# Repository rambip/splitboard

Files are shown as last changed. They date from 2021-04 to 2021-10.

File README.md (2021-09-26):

# Splitboard

This is the ressources we use to create our split, type matrix, bluetooth, mecanical custom keyboard.

Still in construction !

We used a lot of different technologies (solidworks for example), so you probably will not be able to recreate exactly the same keyboard.

But we added ressources you can use if you want to make your own !

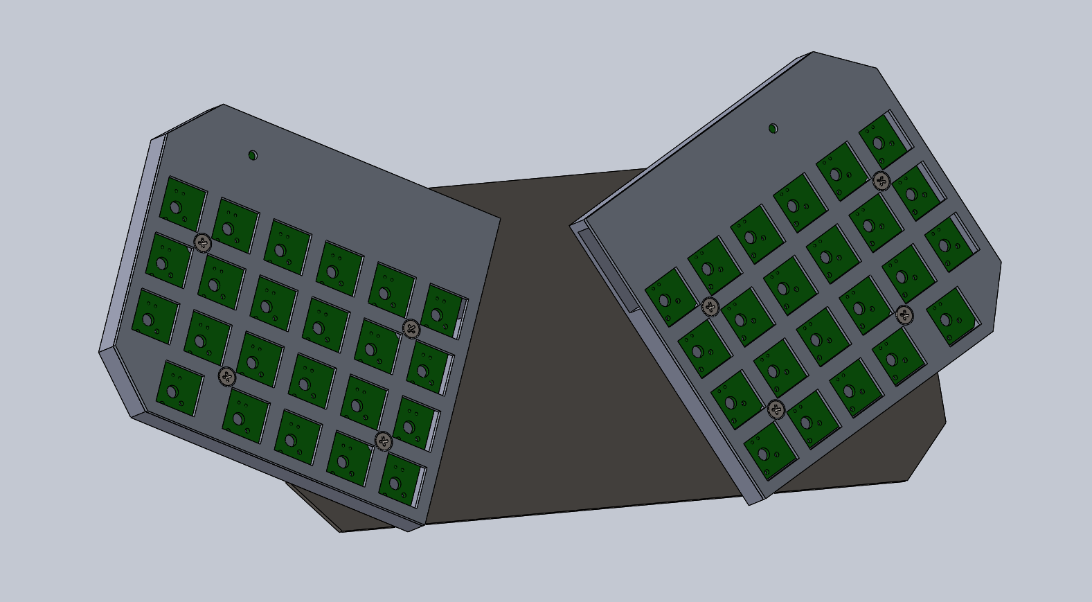
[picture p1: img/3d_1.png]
3d model


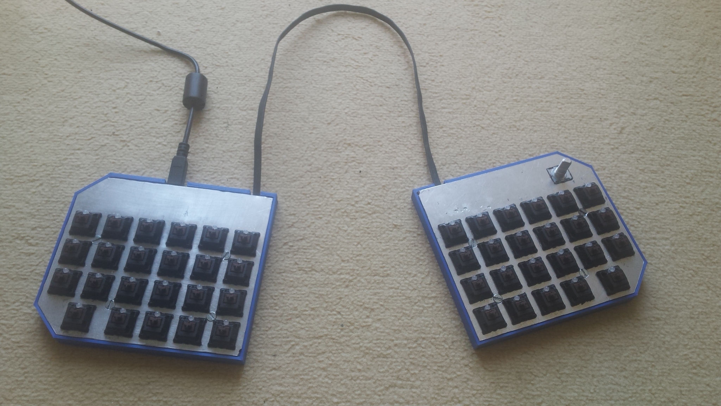
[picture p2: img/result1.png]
result1


## Description

pcb + 3d-printed box + aluminium plate + brown switches + adafruit feather 32u4

### Design goals:

- comfortable
	Ergonomics was the first goal of this model.
	Even if we had to make tradeoffs, the first choices (2 parts, mechanical switches, design of a new layout) were made to increase comfort.

- portable
	It is a tiny keyboard: 46 keys, measure less than 24x12 cm
	Every key has to be reachable without moving your hands at all !

- robust
	I didn't broke it yet !

- usb and bluetooth
        You can use it with any computer (mac or pc) and any modern smartphone

Our keyboard supports usb and bluetooth (BLE) communication with the *hid* specification.

## Content:

 - board design, with all components (kicad and gerber files) → `pcb`
 - ready to print STL files → `printing`
 - 3d modeling of the entire keyboard (solidworks and .step) → `3d`
 - arduino code for card → `code`

## 3d structure:

- box

- pcb

- plate

- switches

We chose the [cherry mx brown](https://www.cherrymx.de/en/mx-original/mx-brown.html).

> Pro tip: Before buying, try to find a second-hand broken keyboard somewhere !

## PCB and electronics:

We used the [adafruit 32u4](https://learn.adafruit.com/adafruit-feather-32u4-bluefruit-le/overview).

Go check out their [github account](https://github.com/adafruit), they have a lot of cool stuff !

## Software:

### Arduino

you can test our sketches if you have a 32u4 adafruit feather.

linux with arduino-cli:

First, make sure you are part of the `uucp` group.
If not, use the command `gpasswd -a $USER uucp`

`arduino-cli core install adafruit:avr`

find the board connected to usb (look at the *Port* path):
`arduino-cli board list` 

`arduino-cli board attach adafruit:avr:feather32u4`
`arduino-cli compile`
`arduino-cli upload`

### Ressources:
https://wiki.osdev.org/USB_Human_Interface_Devices

## TODO:

- [ ] convert all 3d modeling to .step
- [ ] add links to documentation

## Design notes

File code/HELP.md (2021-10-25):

# Help with `arduino-cli` 
If you want to use `arduino-cli` to compile this project, here is a guide:

- installation:
```
# install the avr platform 
arduino-cli core install arduino:avr

# install the adafruit core
arduino-cli core install adafruit:avr --additional-urls https://www.adafruit.com/package_adafruit_index.json

# install lib
arduino-cli lib install "Adafruit BluefruitLE nRF5"

```

- test if board is connected:
```
# test if board detected
arduino-cli board list
```

- compile and upload a sketch:
```
# create sketch.json
arduino-cli attach adafruit:avr:feather32u4
arduino-cli compile 
arduino-cli upload
```

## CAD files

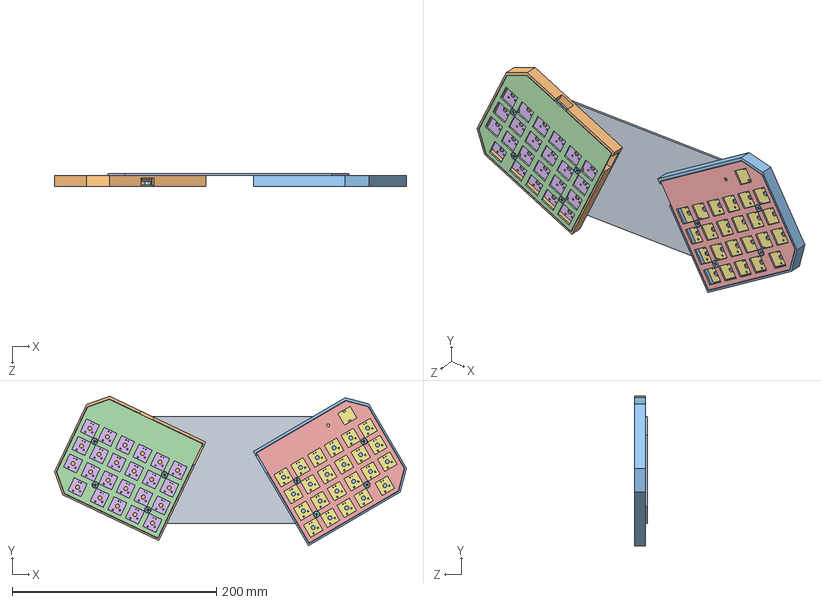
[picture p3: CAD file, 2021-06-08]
3d/Assemblage.STEP
344.8 x 146.5 x 13.1 mm
support
left back
right back
left plate
right plate
left pcb
right pcb
screw_ISO 7046-1 - M3 x 4 - Z - 4N x 8
spacer x 8

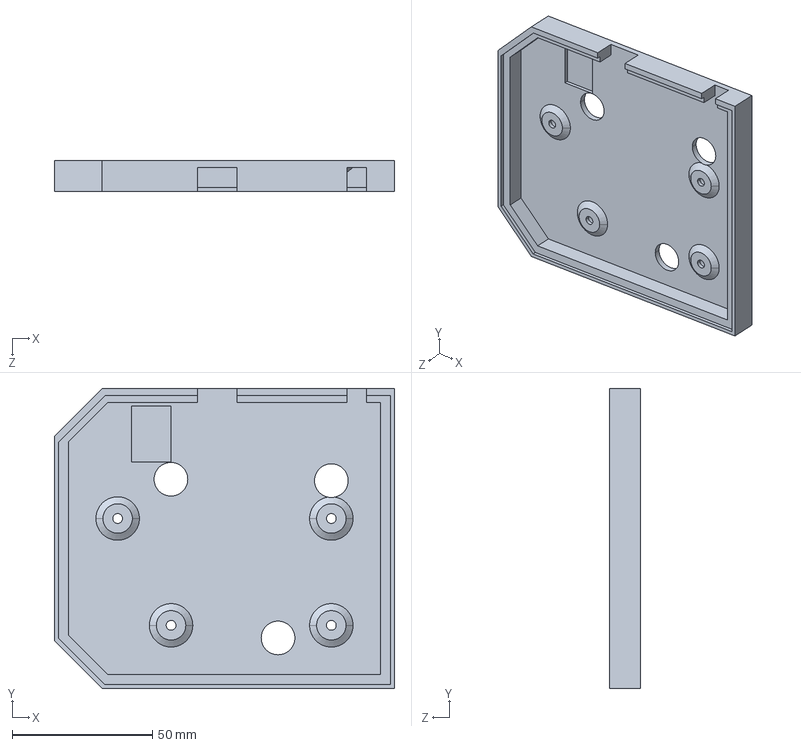
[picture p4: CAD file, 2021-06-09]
3d/left back.STEP
121.3 x 107.0 x 11.1 mm

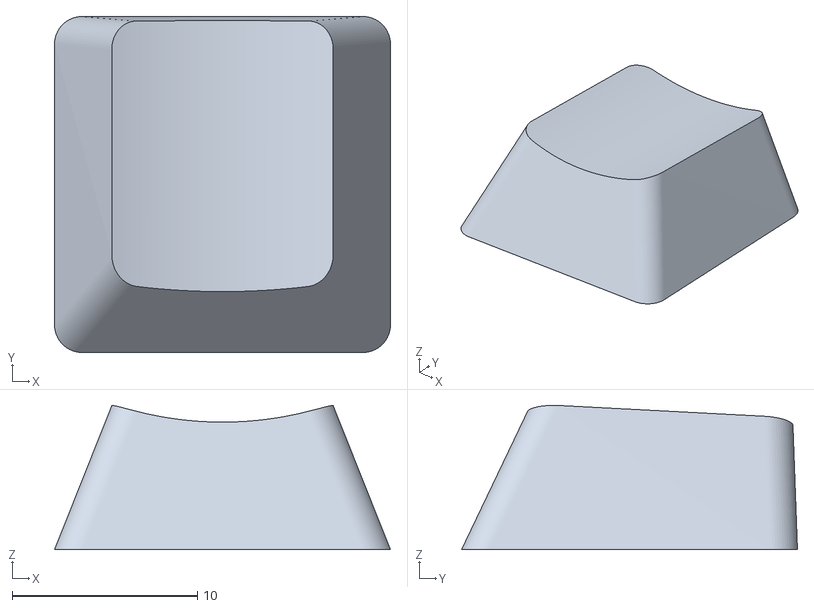
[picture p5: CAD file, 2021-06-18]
printing/keycaps/row_2.stl
18.2 x 18.2 x 7.80

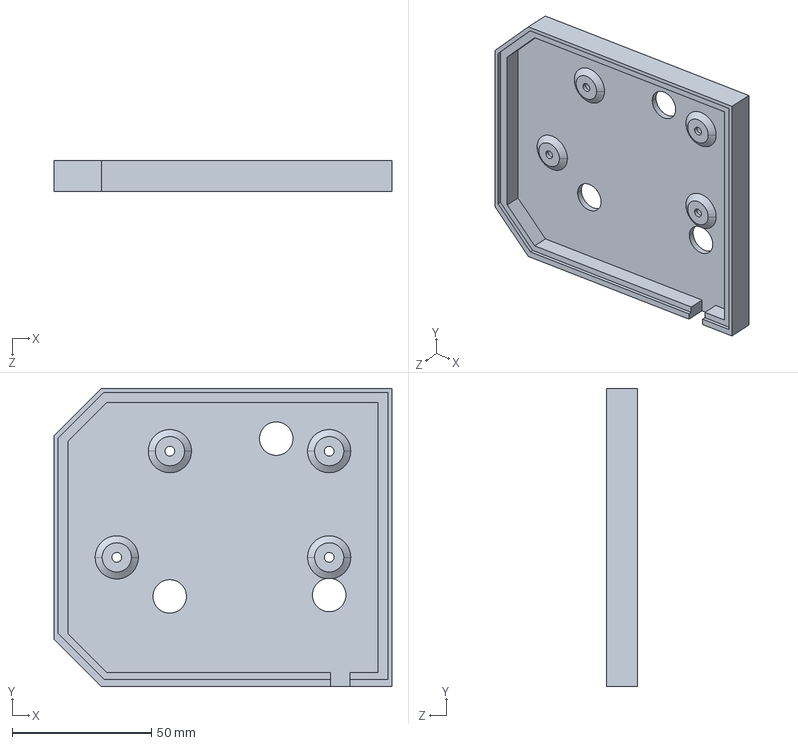
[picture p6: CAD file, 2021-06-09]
3d/right back.STEP
121.3 x 107.0 x 11.1 mm

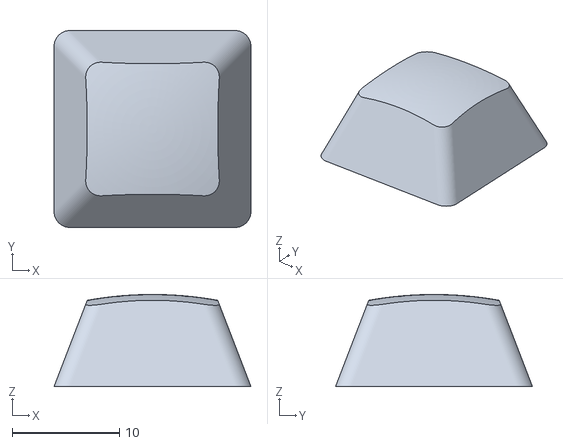
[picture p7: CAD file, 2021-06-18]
printing/keycaps/thumb.stl
18.4 x 18.4 x 8.60

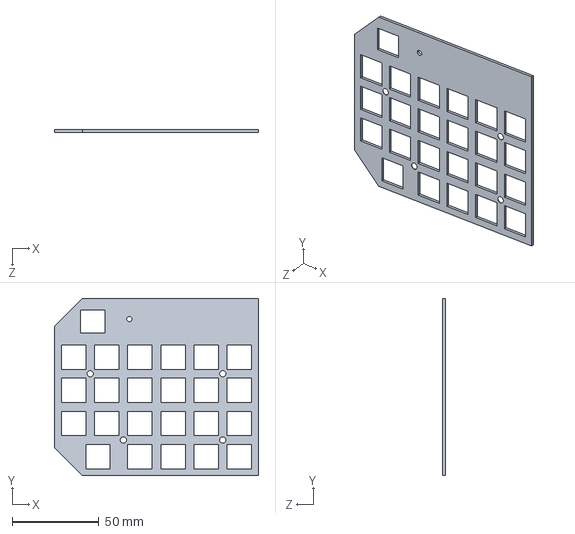
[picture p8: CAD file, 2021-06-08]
3d/right plate.STEP
117.2 x 102.0 x 1.50 mm

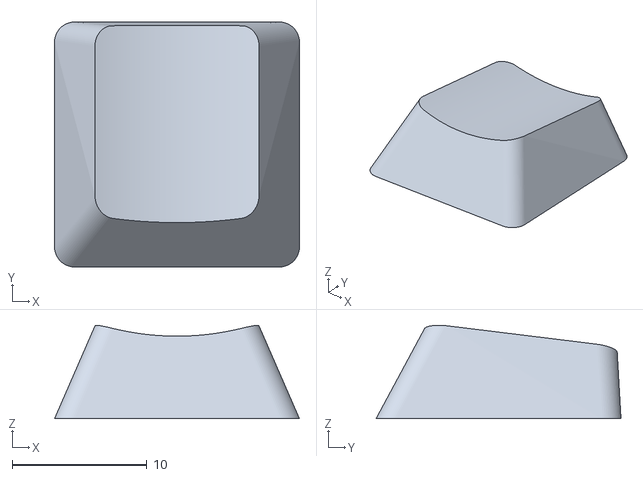
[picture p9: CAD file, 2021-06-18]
printing/keycaps/row_3.stl
18.2 x 18.2 x 6.92

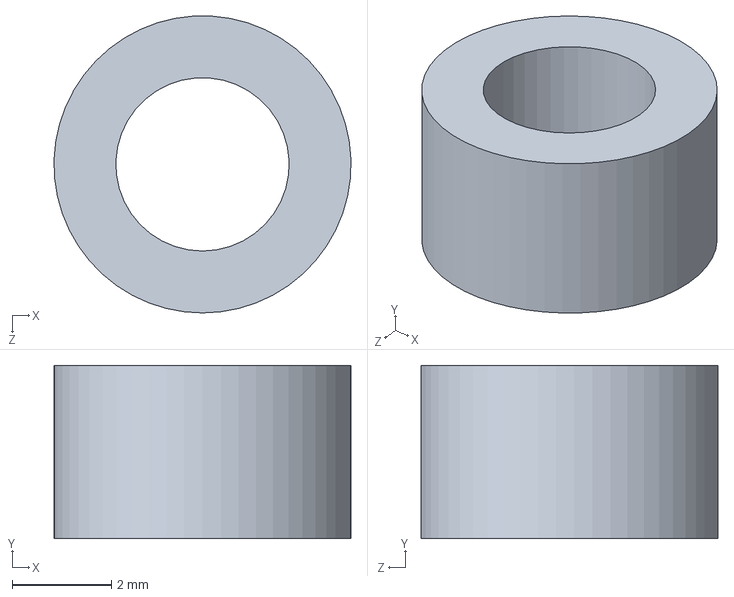
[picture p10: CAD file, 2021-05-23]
3d/spacer.SLDPRT
6.00 x 3.50 x 5.99 mm

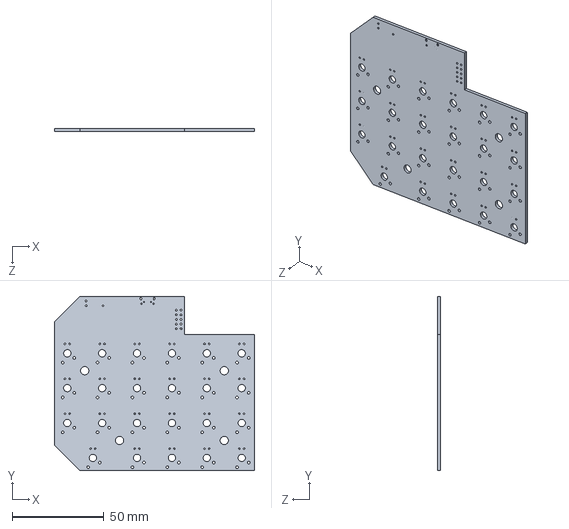
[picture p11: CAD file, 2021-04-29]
3d/left pcb.sldprt
109.2 x 95.2 x 1.60 mm

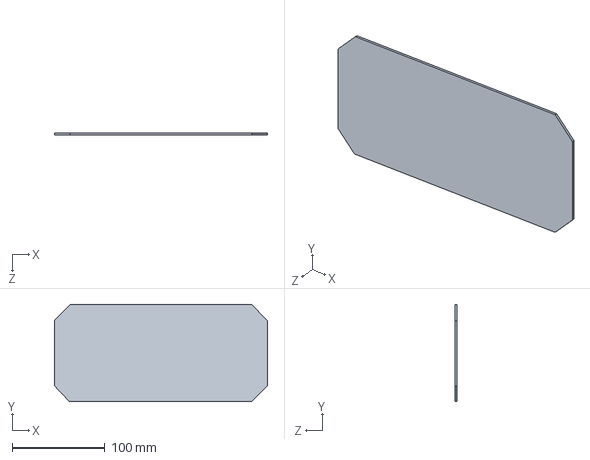
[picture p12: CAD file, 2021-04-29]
3d/support.SLDPRT
230.0 x 105.0 x 2.00 mm

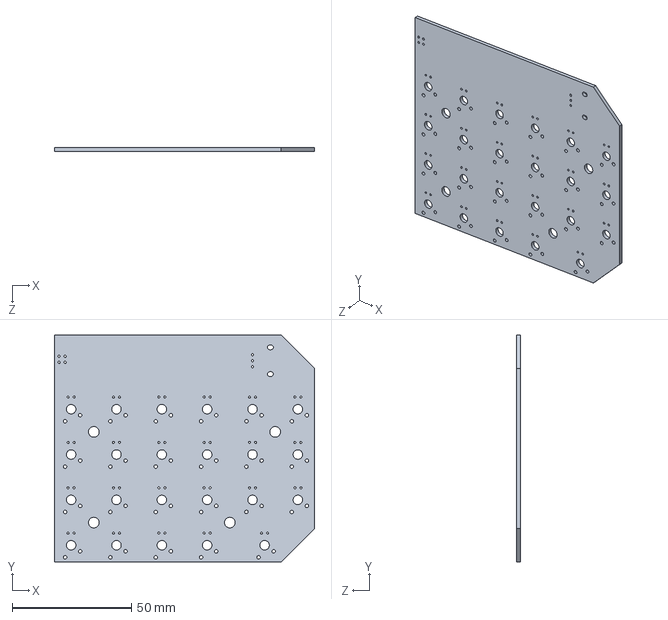
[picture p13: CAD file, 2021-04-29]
3d/right pcb.sldprt
109.2 x 95.2 x 1.60 mm

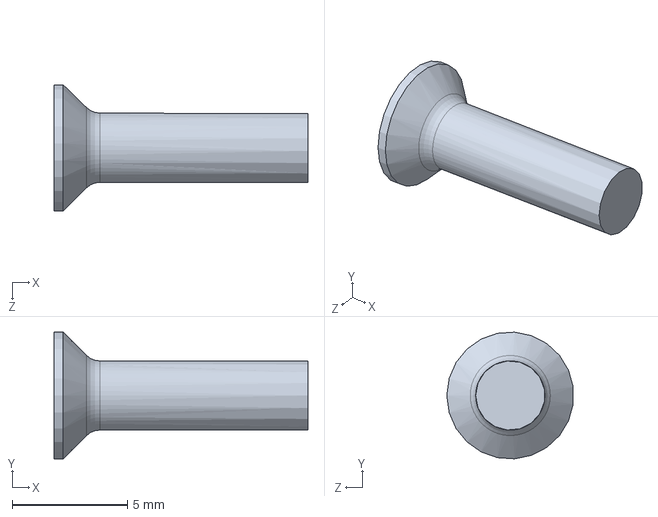
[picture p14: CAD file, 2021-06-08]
3d/screw.SLDPRT
11.0 x 5.49 x 5.47 mm

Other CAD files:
printing/keycaps/row_1.stl
3d/left plate.STEP
3d/Assemblage.SLDASM
3d/left back.SLDPRT
3d/left plate.SLDPRT
3d/right back.SLDPRT
3d/right plate.SLDPRT
printing/left back.STL
printing/right back.STL

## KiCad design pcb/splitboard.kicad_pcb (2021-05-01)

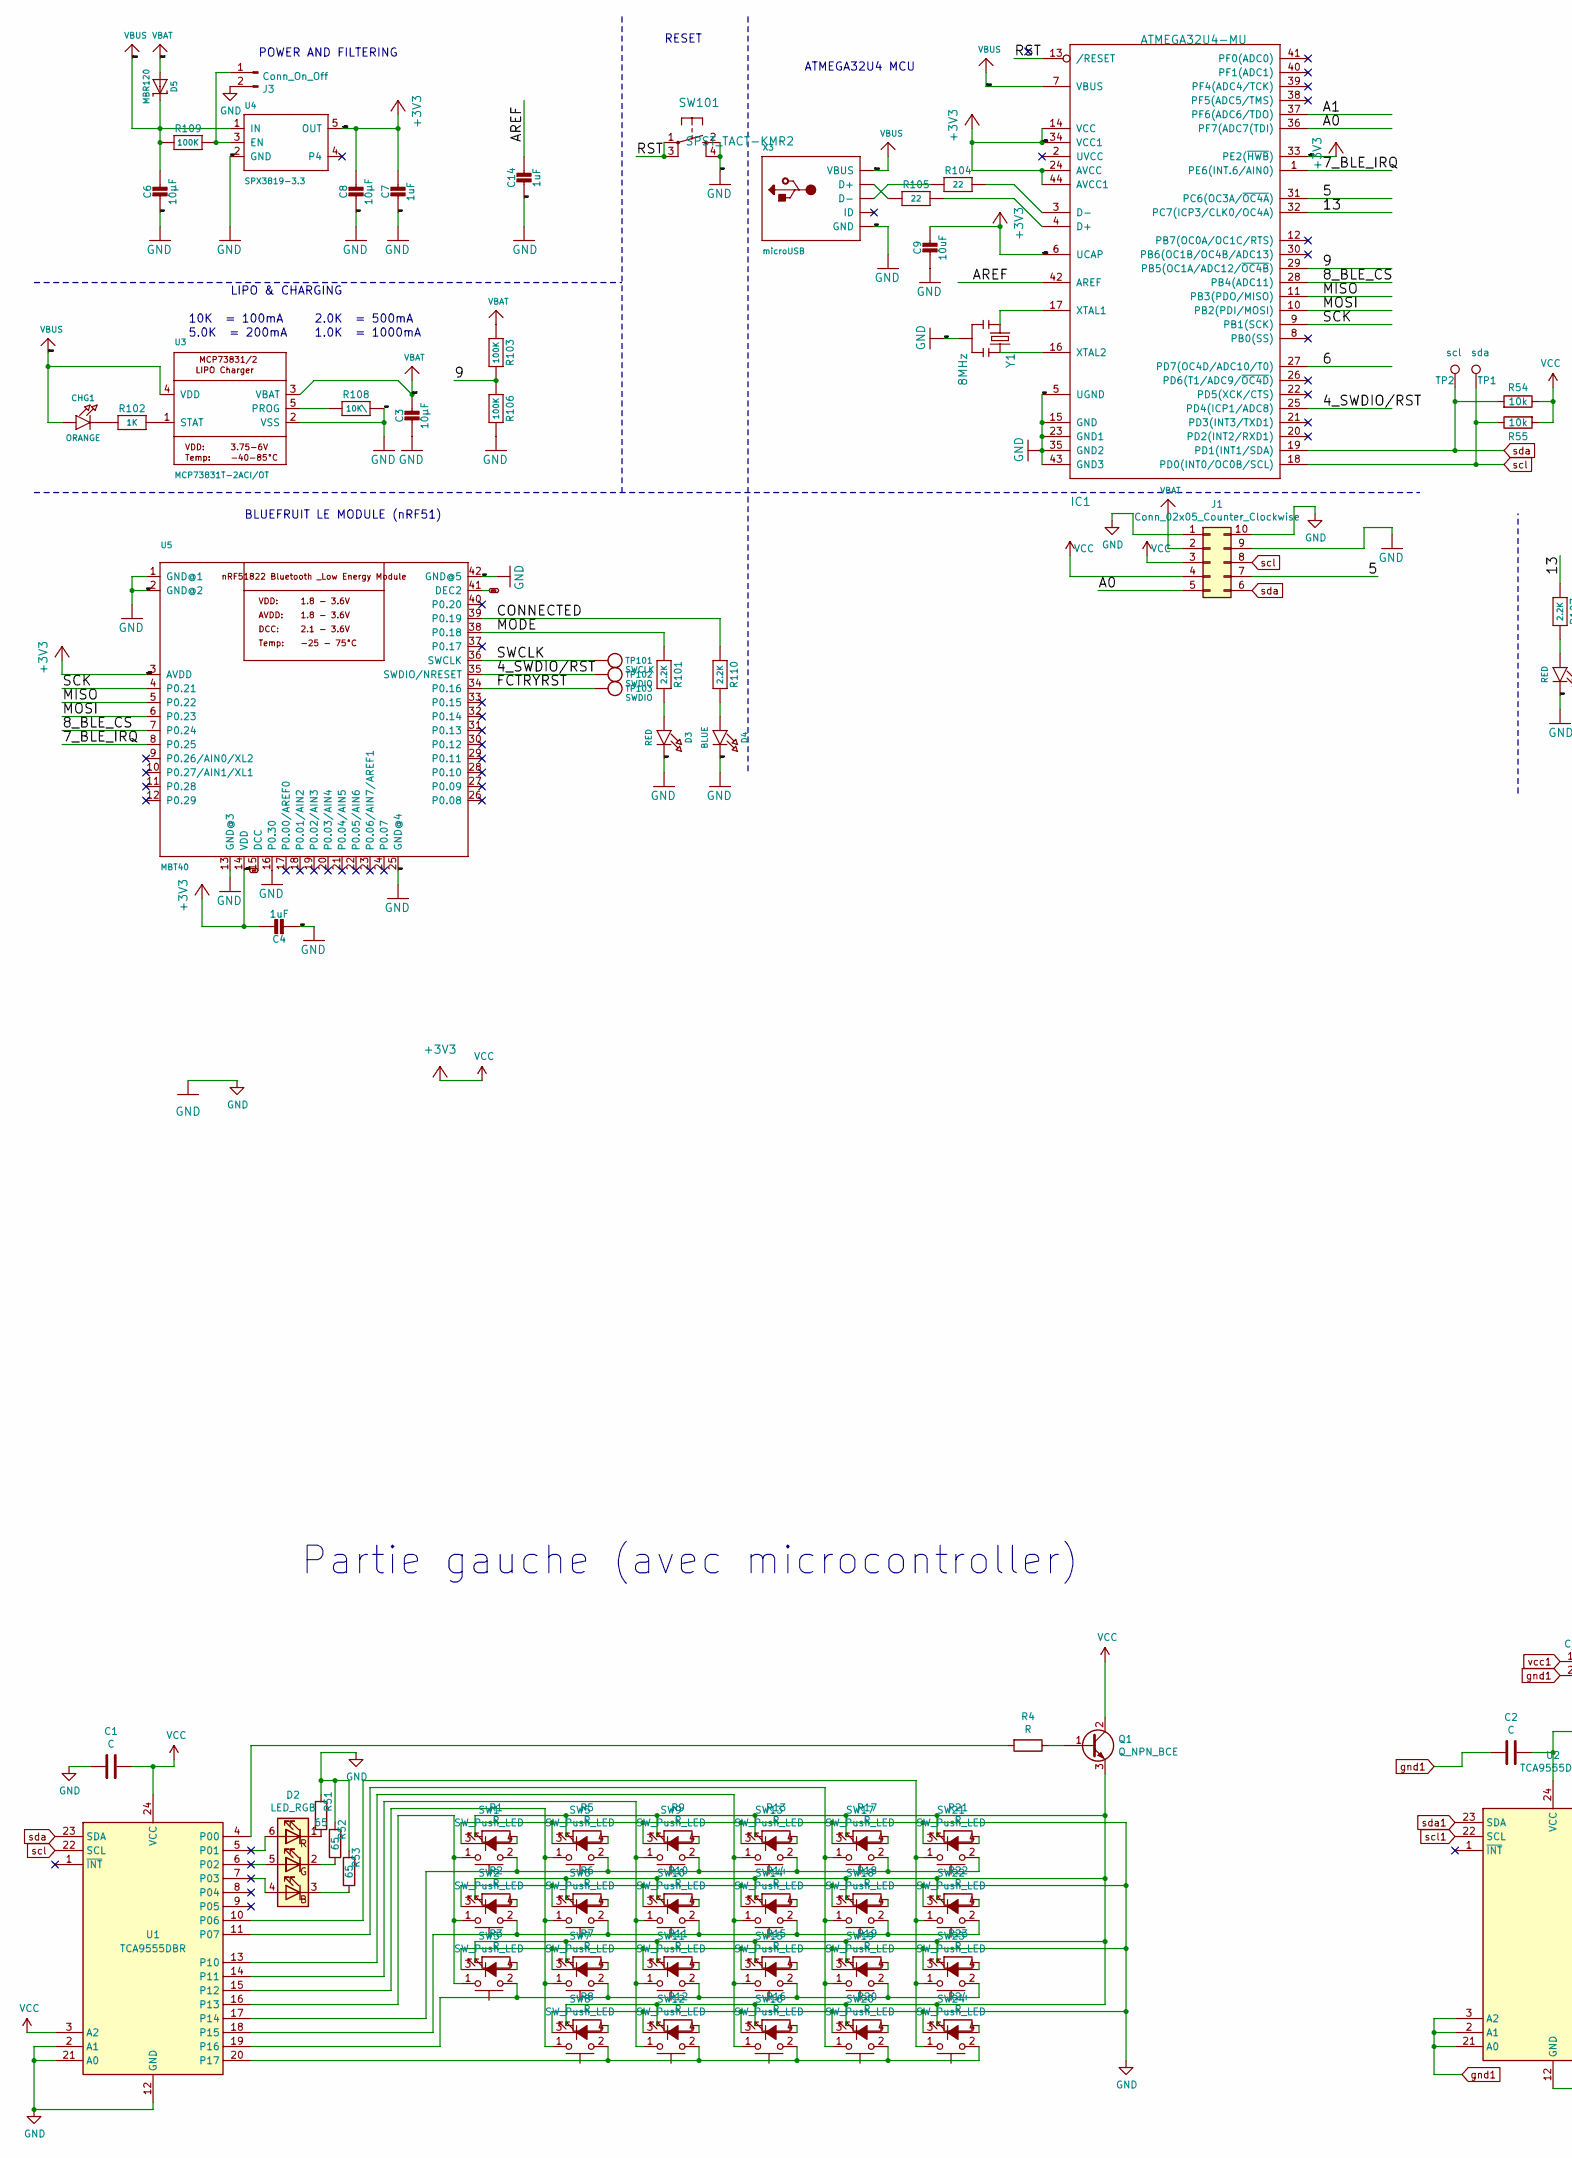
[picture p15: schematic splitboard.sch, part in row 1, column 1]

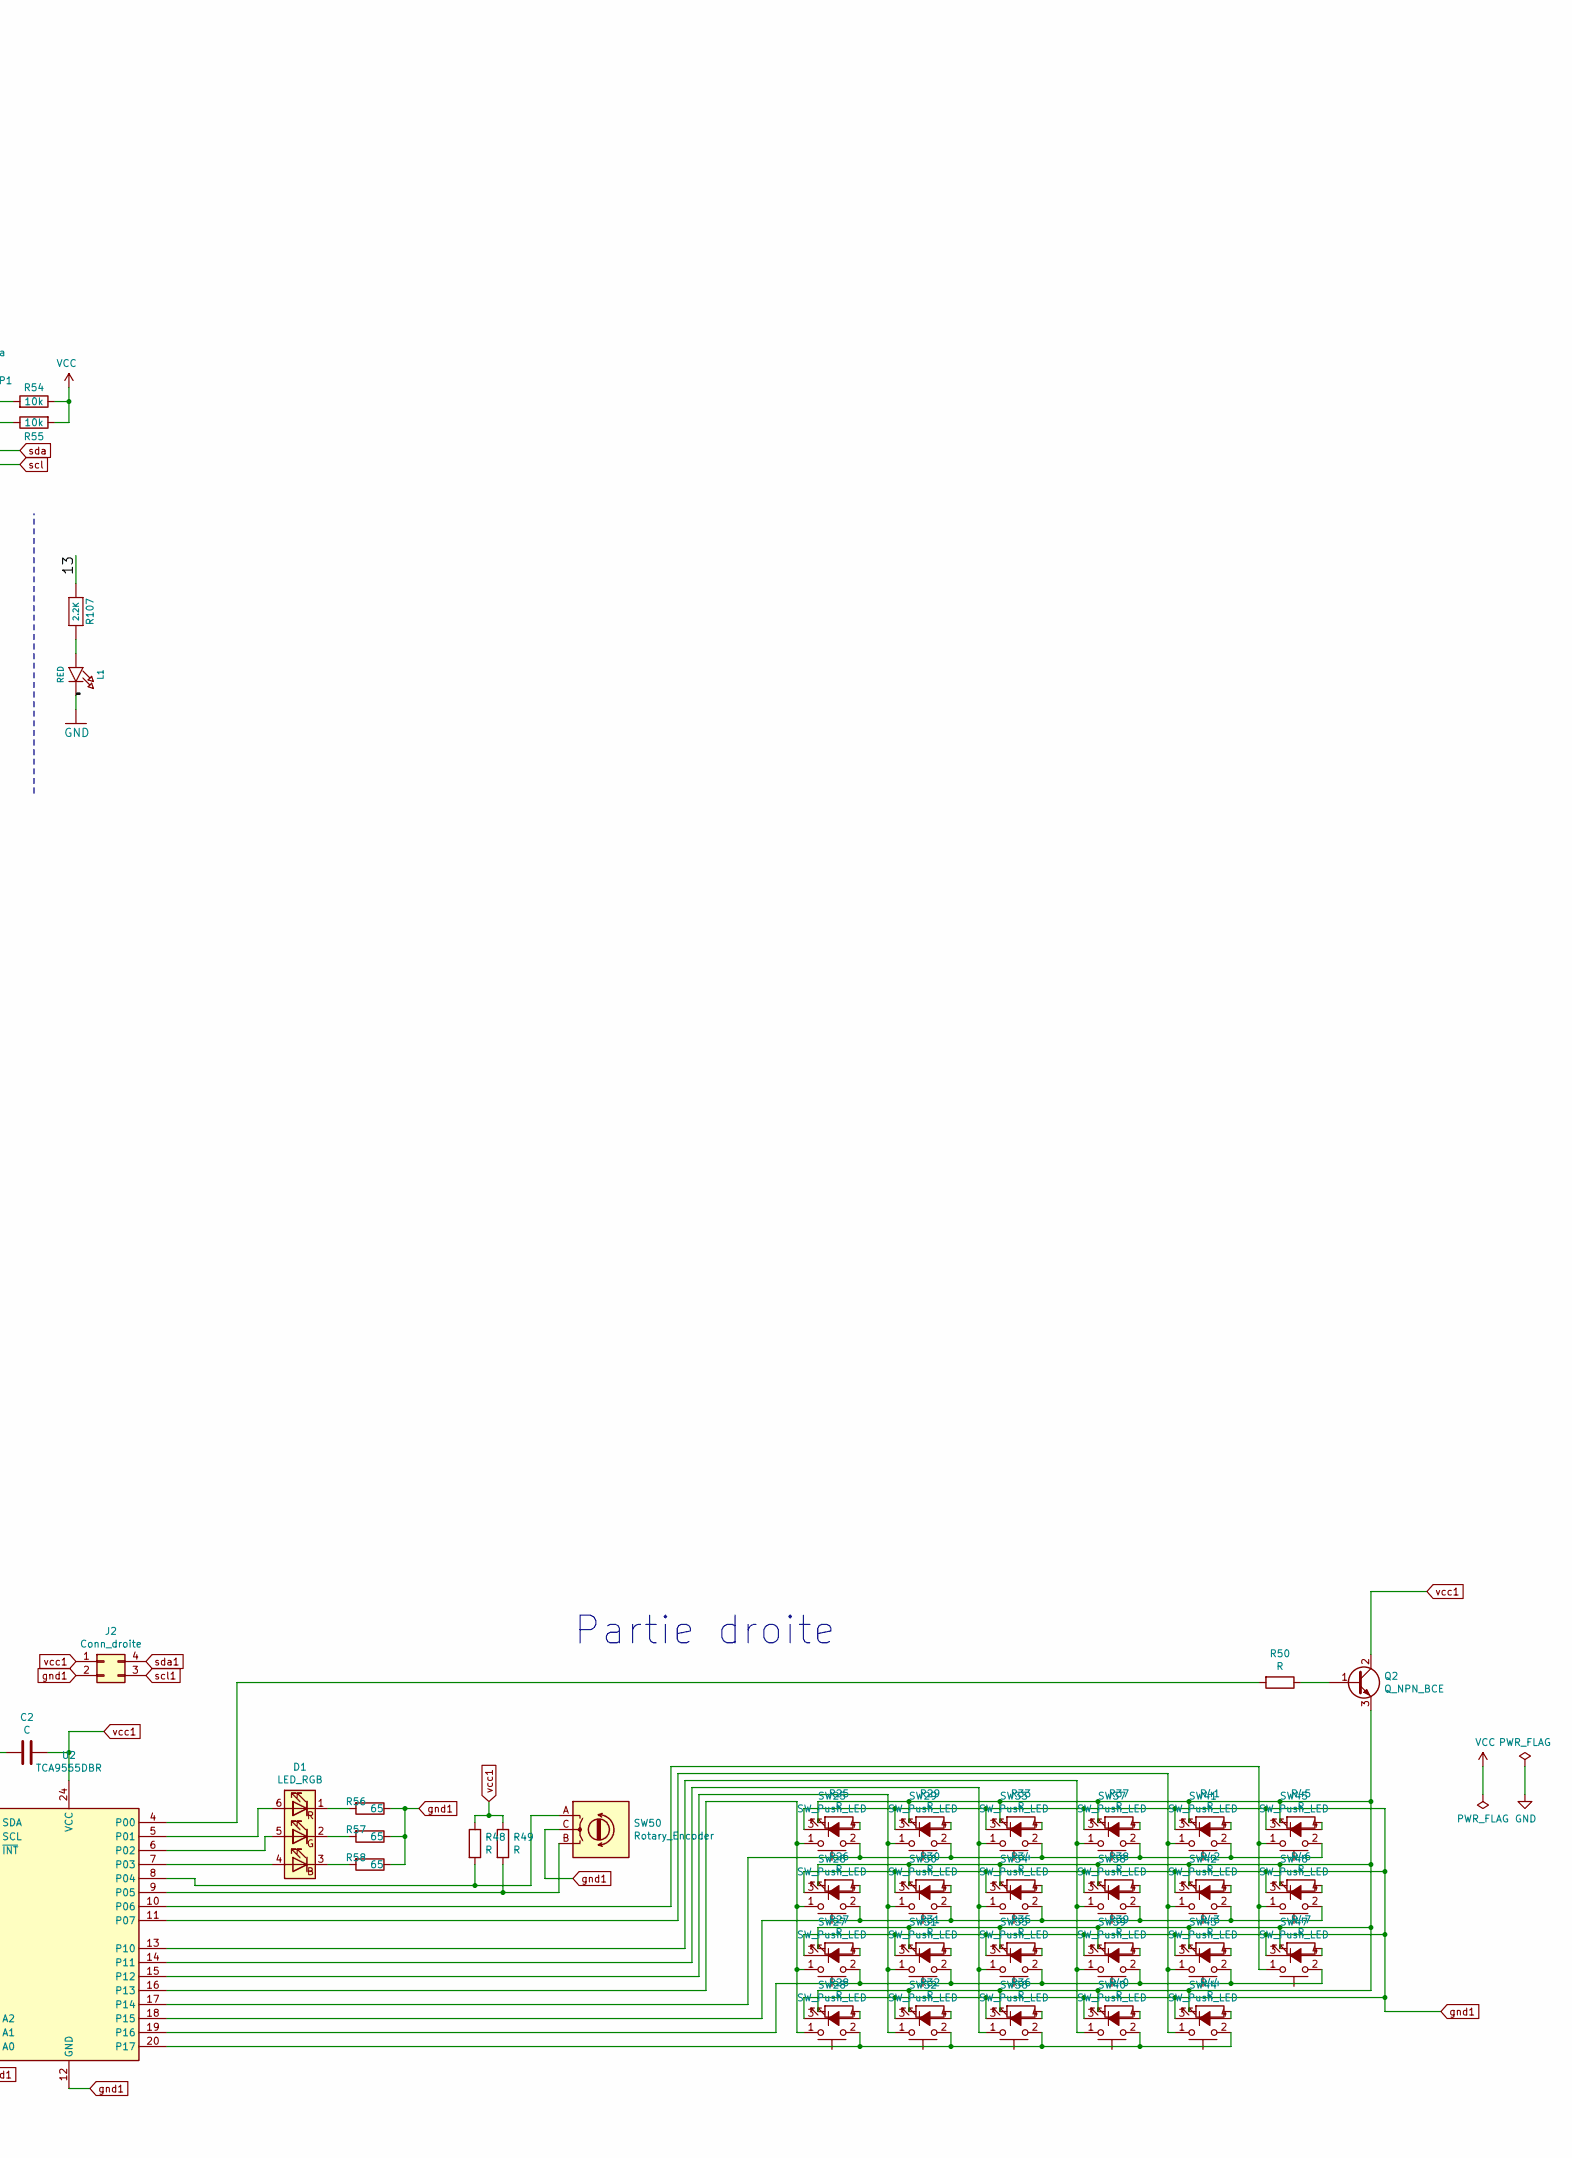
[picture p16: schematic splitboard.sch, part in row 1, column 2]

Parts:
C1, C2: C; C_0603_HandSoldering
C3, C6, C8: 10µF; 0805-NO
C4, C7, C14: 1uF; 0603-NO
C9: 10uF; _0805MP
CHG1: ORANGE; CHIPLED_0805_NOOUTLINE
D1, D2: LED_RGB; LED_WS2812_PLCC6_5.0x5.0mm_P1.6mm
D3: RED; CHIPLED_0805_NOOUTLINE
D4: BLUE; CHIPLED_0805_NOOUTLINE
D5: MBR120; SOD-123
IC1: ATMEGA32U4-MU; TQFN44_7MM
J1: Conn_02x05_Counter_Clockwise; Pin_Header_Straight_2x05_Pitch2.54mm
J2: Conn_droite; PinHeader_2x02_P2.54mm_Vertical
J3: Conn_On_Off; PinHeader_1x02_P2.54mm_Vertical
L1: RED; CHIPLED_0805_NOOUTLINE
Q1, Q2: Q_NPN_BCE; SOT-23
R1, R2, R3, R4, R5, R6, R7, R8, R9, R10, R11, R12, R13, R14, R15, R16, R17, R18, R19, R20, R21, R22, R23, R24, R25, R26, R27, R28, R29, R30, R31, R32, R33, R34, R35, R36, R37, R38, R39, R40, R41, R42, R43, R44, R45, R46, R47, R48, R49, R50: R; R_0603_HandSoldering
R51, R52, R53: 65; R_0201_0603Metric_Pad0.64x0.40mm_HandSolder
R54, R55: 10k; R_0603_HandSoldering
R56, R57, R58: 65; R_0603_HandSoldering
R101, R107, R110: 2.2K; 0603-NO
R102: 1K; 0603-NO
R103, R106, R109: 100K; 0603-NO
R104, R105: 22; 0603-NO
R108: 10K\\; 0603-NO
SW1, SW2, SW3, SW5, SW6, SW7, SW8, SW9, SW10, SW11, SW12, SW13, SW14, SW15, SW16, SW17, SW18, SW19, SW20, SW21, SW22, SW23, SW24, SW25, SW26, SW27, SW28, SW29, SW30, SW31, SW32, SW33, SW34, SW35, SW36, SW37, SW38, SW39, SW40, SW41, SW42, SW43, SW44, SW45, SW46, SW47: SW_Push_LED; SW_Cherry_MX_1.00u_Plate_led
SW50: Rotary_Encoder; RotaryEncoder_Alps_EC12E_Vertical_H20mm
SW101: SPST_TACT-KMR2; KMR2
TP1: sda; TestPoint_Pad_D1.0mm
TP2: scl; TestPoint_Pad_D1.0mm
TP101: SWCLK; PAD-1.5X2.0
TP102, TP103: SWDIO; PAD-1.5X2.0
U1, U2: TCA9555DBR; SSOP-24_5.3x8.2mm_P0.65mm
U3: MCP73831T-2ACI/OT; SOT23-5
U4: SPX3819-3.3; SOT23-5
U5: MBT40; BLE_MODULE_RAYTAC_MDBT40
X3: microUSB; 4UCONN_20329_V2
Y1: 8MHz; RESONATOR-SMD

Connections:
+3V3: C1.1, C4.1, C7.1, C8.1, C9.1, IC1.6 (UCAP), IC1.14 (VCC), IC1.24 (AVCC), IC1.33 (PE2(~HWB)), IC1.34 (VCC1), IC1.44 (AVCC1), J1.3, J1.4, Q1.2 (C), R54.1, R55.2, U1.3 (A2), U1.24 (VCC), U4.5 (OUT), U5.3 (AVDD), U5.14 (VDD)
/4_SWDIO/RST: IC1.25 (PD4(ICP1/ADC8)), TP102.P$1, U5.35 (SWDIO/NRESET)
/5: IC1.31 (PC6(OC3A/~OC4A)), J1.7
/6: IC1.27 (PD7(OC4D/ADC10/T0))
/7_BLE_IRQ: IC1.1 (PE6(INT.6/AIN0)), U5.8 (P0.25)
/8_BLE_CS: IC1.28 (PB4(ADC11)), U5.7 (P0.24)
/9: IC1.29 (PB5(OC1A/ADC12/~OC4B)), R103.2, R106.1
/13: IC1.32 (PC7(ICP3/CLK0/OC4A)), R107.1
/A0: IC1.36 (PF7(ADC7(TDI)), J1.5
/A1: IC1.37 (PF6(ADC6/TDO))
/AREF: C14.1, IC1.42 (AREF)
/CONNECTED: R110.1, U5.39 (P0.19)
/FCTRYRST: TP103.P$1, U5.34 (P0.16)
/MISO: IC1.11 (PB3(PDO/MISO)), U5.5 (P0.22)
/MODE: R101.1, U5.38 (P0.18)
/MOSI: IC1.10 (PB2(PDI/MOSI)), U5.6 (P0.23)
/RST: IC1.13 (/RESET), SW101.1, SW101.3 (P1)
/SCK: IC1.9 (PB1(SCK)), U5.4 (P0.21)
/SWCLK: TP101.P$1, U5.36 (SWCLK)
DCC: U5.15 (DCC)
DEC2: U5.41 (DEC2)
GND: C1.2, C3.2, C4.2, C6.2, C7.2, C8.2, C9.2, C14.2, D3.C, D4.C, IC1.5 (UGND), IC1.15 (GND), IC1.23 (GND1), IC1.35 (GND2), IC1.43 (GND3), J1.1, J1.9, J1.10, J3.2, L1.C, R51.2, R52.2, R53.2, R106.2, R108.2, SW1.3 (K), SW2.3 (K), SW3.3 (K), SW5.3 (K), SW6.3 (K), SW7.3 (K), SW8.3 (K), SW9.3 (K), SW10.3 (K), SW11.3 (K), SW12.3 (K), SW13.3 (K), SW14.3 (K), SW15.3 (K), SW16.3 (K), SW17.3 (K), SW18.3 (K), SW19.3 (K), SW20.3 (K), SW21.3 (K), SW22.3 (K), SW23.3 (K), SW24.3 (K), SW101.2 (S), SW101.4 (S1), U1.2 (A1), U1.12 (GND), U1.21 (A0), U3.2 (VSS), U4.2 (GND), U5.1 (GND@1), U5.2 (GND@2), U5.13 (GND@3), U5.16 (P0.30), U5.25 (GND@4), U5.42 (GND@5), X3.BASE@1 (GND), X3.BASE@2 (GND), X3.GND, X3.SPRT@1 (GND), X3.SPRT@2 (GND), X3.SPRT@3 (GND), X3.SPRT@4 (GND), Y1.2
unnamed: CHG1.C, R102.1
unnamed: D1.1 (RK), R56.2
unnamed: D1.2 (GK), R57.2
unnamed: D1.3 (BK), R58.2
unnamed: D1.4 (BA), U2.7 (P03)
unnamed: D1.5 (GA), U2.6 (P02)
unnamed: D1.6 (RA), U2.5 (P01)
unnamed: D2.1 (RK), R51.1
unnamed: D2.2 (GK), R52.1
unnamed: D2.3 (BK), R53.1
unnamed: D2.4 (BA), U1.7 (P03)
unnamed: D2.5 (GA), U1.6 (P02)
unnamed: D2.6 (RA), U1.5 (P01)
unnamed: D3.A, R101.2
unnamed: D4.A, R110.2
unnamed: IC1.3 (D-), R104.2
unnamed: IC1.4 (D+), R105.2
unnamed: IC1.16 (XTAL2), Y1.3
unnamed: IC1.17 (XTAL1), Y1.1
unnamed: J3.1, R109.2, U4.3 (EN)
unnamed: L1.A, R107.2
unnamed: Q1.1 (B), R4.1
unnamed: Q1.3 (E), R1.2, R2.2, R3.2, R5.2, R6.2, R7.2, R8.2, R9.2, R10.2, R11.2, R12.2, R13.2, R14.2, R15.2, R16.2, R17.2, R18.2, R19.2, R20.2, R21.2, R22.2, R23.2, R24.2
unnamed: Q2.1 (B), R50.1
unnamed: Q2.3 (E), R25.2, R26.2, R27.2, R28.2, R29.2, R30.2, R31.2, R32.2, R33.2, R34.2, R35.2, R36.2, R37.2, R38.2, R39.2, R40.2, R41.2, R42.2, R43.2, R44.2, R45.2, R46.2, R47.2
unnamed: R1.1, SW1.4 (A)
unnamed: R2.1, SW2.4 (A)
unnamed: R3.1, SW3.4 (A)
unnamed: R4.2, U1.4 (P00)
unnamed: R5.1, SW5.4 (A)
unnamed: R6.1, SW6.4 (A)
unnamed: R7.1, SW7.4 (A)
unnamed: R8.1, SW8.4 (A)
unnamed: R9.1, SW9.4 (A)
unnamed: R10.1, SW10.4 (A)
unnamed: R11.1, SW11.4 (A)
unnamed: R12.1, SW12.4 (A)
unnamed: R13.1, SW13.4 (A)
unnamed: R14.1, SW14.4 (A)
unnamed: R15.1, SW15.4 (A)
unnamed: R16.1, SW16.4 (A)
unnamed: R17.1, SW17.4 (A)
unnamed: R18.1, SW18.4 (A)
unnamed: R19.1, SW19.4 (A)
unnamed: R20.1, SW20.4 (A)
unnamed: R21.1, SW21.4 (A)
unnamed: R22.1, SW22.4 (A)
unnamed: R23.1, SW23.4 (A)
unnamed: R24.1, SW24.4 (A)
unnamed: R25.1, SW25.4 (A)
unnamed: R26.1, SW26.4 (A)
unnamed: R27.1, SW27.4 (A)
unnamed: R28.1, SW28.4 (A)
unnamed: R29.1, SW29.4 (A)
unnamed: R30.1, SW30.4 (A)
unnamed: R31.1, SW31.4 (A)
unnamed: R32.1, SW32.4 (A)
unnamed: R33.1, SW33.4 (A)
unnamed: R34.1, SW34.4 (A)
unnamed: R35.1, SW35.4 (A)
unnamed: R36.1, SW36.4 (A)
unnamed: R37.1, SW37.4 (A)
unnamed: R38.1, SW38.4 (A)
unnamed: R39.1, SW39.4 (A)
unnamed: R40.1, SW40.4 (A)
unnamed: R41.1, SW41.4 (A)
unnamed: R42.1, SW42.4 (A)
unnamed: R43.1, SW43.4 (A)
unnamed: R44.1, SW44.4 (A)
unnamed: R45.1, SW45.4 (A)
unnamed: R46.1, SW46.4 (A)
unnamed: R47.1, SW47.4 (A)
unnamed: R48.2, SW50.A, U2.8 (P04)
unnamed: R49.2, SW50.B, U2.9 (P05)
unnamed: R50.2, U2.4 (P00)
unnamed: R102.2, U3.1 (STAT)
unnamed: R104.1, X3.D-
unnamed: R105.1, X3.D+
unnamed: R108.1, U3.5 (PROG)
unnamed: SW1.1, SW2.1, SW3.1, U1.16 (P13)
unnamed: SW1.2, SW5.2, SW9.2, SW13.2, SW17.2, SW21.2, U1.17 (P14)
unnamed: SW5.1, SW6.1, SW7.1, SW8.1, U1.15 (P12)
unnamed: SW9.1, SW10.1, SW11.1, SW12.1, U1.14 (P11)
unnamed: SW2.2, SW6.2, SW10.2, SW14.2, SW18.2, SW22.2, U1.18 (P15)
unnamed: SW3.2, SW7.2, SW11.2, SW15.2, SW19.2, SW23.2, U1.19 (P16)
unnamed: SW8.2, SW12.2, SW16.2, SW20.2, SW24.2, U1.20 (P17)
unnamed: SW13.1, SW14.1, SW15.1, SW16.1, U1.13 (P10)
unnamed: SW17.1, SW18.1, SW19.1, SW20.1, U1.11 (P07)
unnamed: SW21.1, SW22.1, SW23.1, SW24.1, U1.10 (P06)
unnamed: SW25.1, SW26.1, SW27.1, SW28.1, U2.16 (P13)
unnamed: SW25.2, SW29.2, SW33.2, SW37.2, SW41.2, SW45.2, U2.17 (P14)
unnamed: SW26.2, SW30.2, SW34.2, SW38.2, SW42.2, SW46.2, U2.18 (P15)
unnamed: SW27.2, SW31.2, SW35.2, SW39.2, SW43.2, SW47.2, U2.19 (P16)
unnamed: SW28.2, SW32.2, SW36.2, SW40.2, SW44.2, U2.20 (P17)
unnamed: SW29.1, SW30.1, SW31.1, SW32.1, U2.15 (P12)
unnamed: SW33.1, SW34.1, SW35.1, SW36.1, U2.14 (P11)
unnamed: SW37.1, SW38.1, SW39.1, SW40.1, U2.13 (P10)
unnamed: SW41.1, SW42.1, SW43.1, SW44.1, U2.11 (P07)
unnamed: SW45.1, SW46.1, SW47.1, U2.10 (P06)
VBAT: C3.1, D5.A, J1.2, R103.1, U3.3 (VBAT)
VBUS: C6.1, CHG1.A, D5.C, IC1.7 (VBUS), R109.1, U3.4 (VDD), U4.1 (IN), X3.VBUS
gnd1: C2.2, J2.2, R56.1, R57.1, R58.1, SW25.3 (K), SW26.3 (K), SW27.3 (K), SW28.3 (K), SW29.3 (K), SW30.3 (K), SW31.3 (K), SW32.3 (K), SW33.3 (K), SW34.3 (K), SW35.3 (K), SW36.3 (K), SW37.3 (K), SW38.3 (K), SW39.3 (K), SW40.3 (K), SW41.3 (K), SW42.3 (K), SW43.3 (K), SW44.3 (K), SW45.3 (K), SW46.3 (K), SW47.3 (K), SW50.C, U2.2 (A1), U2.3 (A2), U2.12 (GND), U2.21 (A0)
scl: IC1.18 (PD0(INT0/OC0B/SCL)), J1.8, R55.1, TP1.1, U1.22 (SCL)
scl1: J2.3, U2.22 (SCL)
sda: IC1.19 (PD1(INT1/SDA)), J1.6, R54.2, TP2.1, U1.23 (SDA)
sda1: J2.4, U2.23 (SDA)
vcc1: C2.1, J2.1, Q2.2 (C), R48.1, R49.1, U2.24 (VCC)

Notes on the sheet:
Partie gauche (avec microcontroller)
Partie droite
POWER AND FILTERING
BLUEFRUIT LE MODULE (nRF51)
RESET
ATMEGA32U4 MCU
10K = 100mA
5.0K = 200mA
2.0K = 500mA
1.0K = 1000mA
LIPO & CHARGING

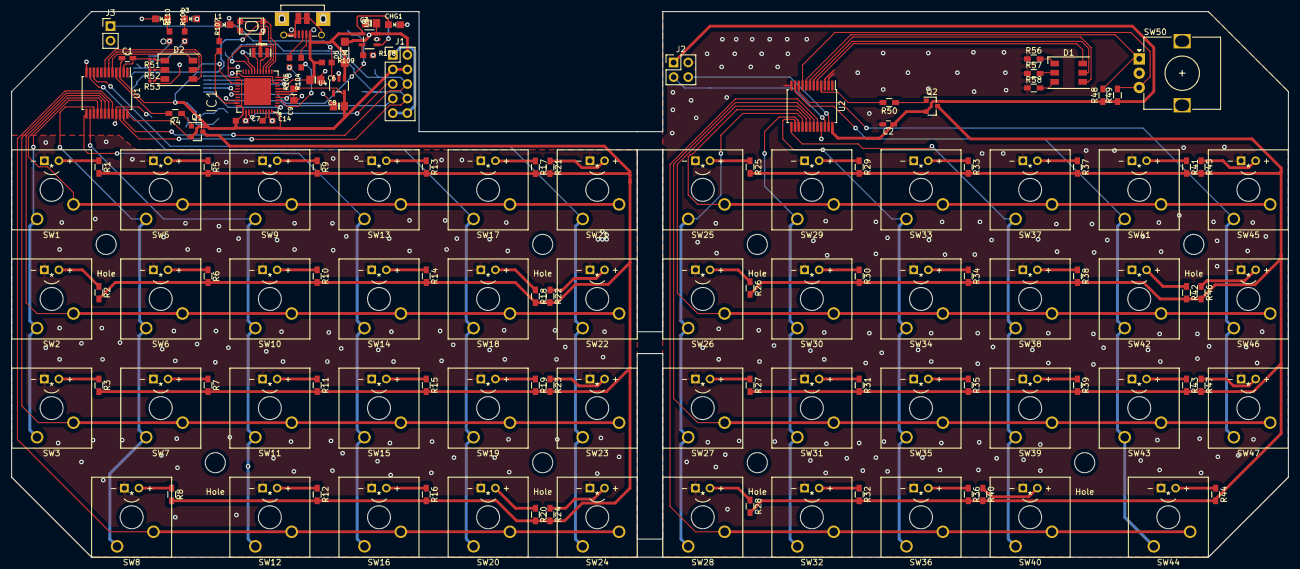
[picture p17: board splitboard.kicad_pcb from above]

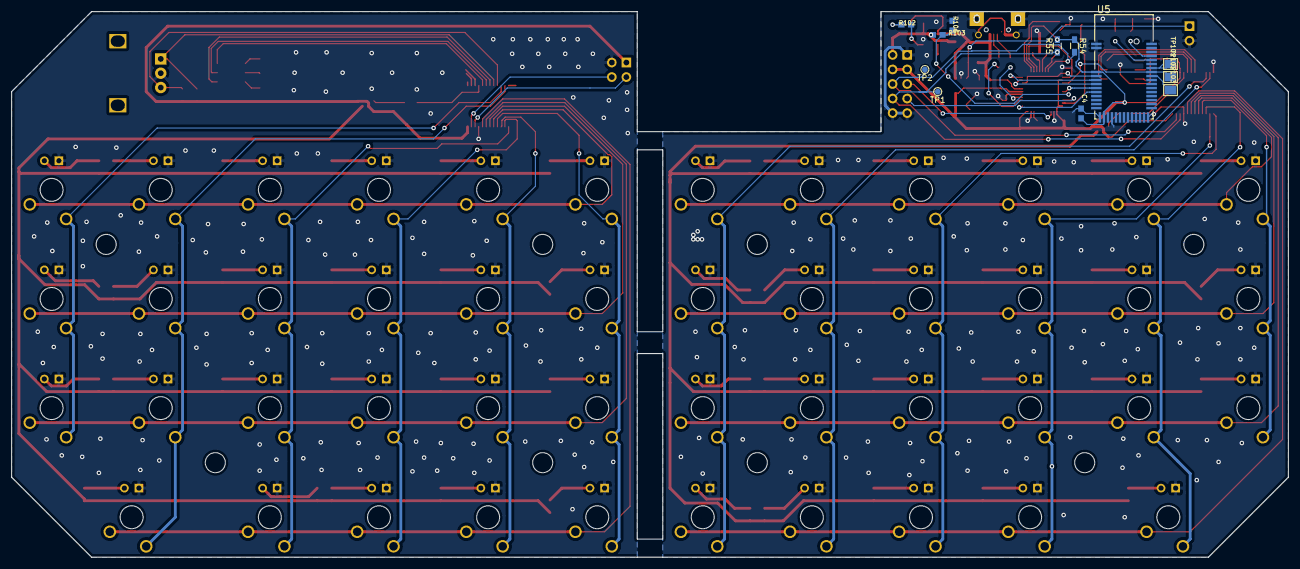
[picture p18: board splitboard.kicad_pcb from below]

Board: 2 copper layers, 222.9 x 95.2 mm, 158 parts (12 on the bottom side), 125 nets.

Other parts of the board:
Hole: M3; screwhole
Hole#2, Hole#3, Hole#4, Hole#5, Hole#6, Hole#7, Hole#8: M3; screwhole

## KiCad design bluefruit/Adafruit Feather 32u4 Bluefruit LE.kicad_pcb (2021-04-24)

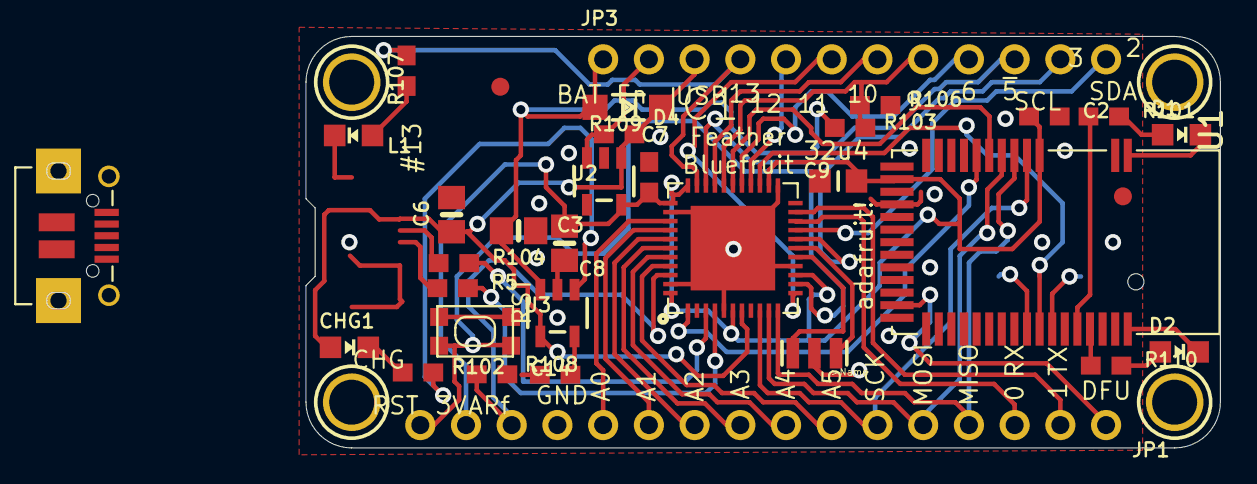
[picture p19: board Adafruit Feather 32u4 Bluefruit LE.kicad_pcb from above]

Board: 2 copper layers, 50.8 x 22.9 mm, 40 parts (0 on the bottom side), 47 nets.

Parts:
C2, C7, C14: 1uF; 0603-NO
C3, C6, C8: 10µF; 0805-NO
C9: 10uF; _0805MP
CHG1: ORANGE; CHIPLED_0805_NOOUTLINE
D1: RED; CHIPLED_0805_NOOUTLINE
D2: BLUE; CHIPLED_0805_NOOUTLINE
D4: MBR120; SOD-123
IC1: ATMEGA32U4-MU; TQFN44_7MM
JP1: HEADER-1X16ROUND; 1X16_ROUND
JP3: HEADER-1X12; 1X12_ROUND
L1: RED; CHIPLED_0805_NOOUTLINE
R5, R104: 22; 0603-NO
R101, R107, R110: 2.2K; 0603-NO
R102: 1K; 0603-NO
R103, R106, R109: 100K; 0603-NO
R108: 10K\; 0603-NO
SW1: SPST_TACT-KMR2; KMR2
TP1: SWCLK; PAD-1.5X2.0
TP2, TP3: SWDIO; PAD-1.5X2.0
U1: MBT40; BLE_MODULE_RAYTAC_MDBT40
U2: SPX3819-3.3; SOT23-5
U3: MCP73831T-2ACI/OT; SOT23-5
U$6, U$24, U$31, U$32: MOUNTINGHOLE2.5; MOUNTINGHOLE_2.5_PLATED
U$34, U$35: FIDUCIAL; FIDUCIAL_1MM
X3: microUSB; 4UCONN_20329_V2
Y1: 8MHz; RESONATOR-SMD

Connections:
+3V3: C2.1, C7.1, C8.1, C9.1, IC1.6, IC1.14, IC1.24, IC1.33, IC1.34, IC1.44, JP1.15, U1.3, U1.14, U2.5
/0: IC1.20, JP1.3
/1: IC1.21, JP1.2
/2: IC1.19, JP3.12
/3: IC1.18, JP3.11
/4_SWDIO/RST: IC1.25, TP2.P$1, U1.35
/5: IC1.31, JP3.10
/6: IC1.27, JP3.9
/7_BLE_IRQ: IC1.1, U1.8
/8_BLE_CS: IC1.28, U1.7
/9: IC1.29, JP3.8, R103.2, R106.1
/10: IC1.30, JP3.7
/11: IC1.12, JP3.6
/12: IC1.26, JP3.5
/13: IC1.32, JP3.4, R107.1
/A0: IC1.36, JP1.12
/A1: IC1.37, JP1.11
/A2: IC1.38, JP1.10
/A3: IC1.39, JP1.9
/A4: IC1.40, JP1.8
/A5: IC1.41, JP1.7
/AREF: C14.1, IC1.42, JP1.14
/CONNECTED: R110.1, U1.39
/DFU: JP1.1, U1.24
/EN: JP3.2, R109.2, U2.3
/FCTRYRST: TP3.P$1, U1.34
/MISO: IC1.11, JP1.4, U1.5
/MODE: R101.1, U1.38
/MOSI: IC1.10, JP1.5, U1.6
/RST: IC1.13, JP1.16, SW1.1, SW1.3
/SCK: IC1.9, JP1.6, U1.4
/SWCLK: TP1.P$1, U1.36
GND: C2.2, C3.2, C6.2, C7.2, C8.2, C9.2, C14.2, D1.C, D2.C, IC1.5, IC1.15, IC1.23, IC1.35, IC1.43, JP1.13, L1.C, R106.2, R108.2, SW1.2, SW1.4, U1.1, U1.2, U1.13, U1.16, U1.25, U1.42, U2.2, U3.2, X3.BASE@1, X3.BASE@2, X3.GND, X3.SPRT@1, X3.SPRT@2, X3.SPRT@3, X3.SPRT@4, Y1.2
unnamed: CHG1.C, R102.1
unnamed: D1.A, R101.2
unnamed: D2.A, R110.2
unnamed: IC1.3, R104.2
unnamed: IC1.4, R5.2
unnamed: IC1.16, Y1.3
unnamed: IC1.17, Y1.1
unnamed: L1.A, R107.2
unnamed: R5.1, X3.D+
unnamed: R102.2, U3.1
unnamed: R104.1, X3.D-
unnamed: R108.1, U3.5
VBAT: C3.1, D4.A, JP3.1, R103.1, U3.3
VBUS: C6.1, CHG1.A, D4.C, IC1.7, JP3.3, R109.1, U2.1, U3.4, X3.VBUS

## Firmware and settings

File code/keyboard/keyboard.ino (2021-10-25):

#include <Arduino.h>

#include "config.h"

#include "Keyboard_get.h"
#include "Keyboard_send.h"
#include "Keyboard_ble.h"

void setup()
{
    Serial.begin(9600);
    setup_hid();
    setup_i2c();
    setup_ble();
}

bool last_time_layer_key = false;

void loop()
{
    // store every key-press detected in the "matrix" table
    int n_keys_pressed = read_keys();

    // look if layer key pressed (bottom keys)
    bool layer_key = matrix[SYMB_LAYER] || matrix[NUM_LAYER] || matrix[SHIFT_LAYER]
                     || matrix[FUNC_LAYER] || matrix[MM_LAYER];

    if ( n_keys_pressed > 0 && last_time_layer_key && !layer_key) {
        // if I just released a layer key, I wait until all keys are released.
        // Otherwise when I release a layer key, the symbol from the base layer
        // could be treagered.
        send_keys(_release_keys);
        send_keys_ble(_release_keys);
        while (n_keys_pressed > 0) {
            n_keys_pressed = read_keys();
        }
        // restart in a normal state.
        last_time_layer_key = false;
        return;
    }

    // update last layer key
    last_time_layer_key = layer_key;

    if (rotary_encoder == RE2) {
        // clockwise rotation
        current_keymap = 1;
        rotary_encoder = REN;
    }
    if (rotary_encoder == RE1) {
        // anticlockwise rotation
        current_keymap = 0;
        rotary_encoder = REN;
    }

    // empty usb-hid report that we will send to the OS
    byte hid_report[8] = {0, 0, 0, 0, 0, 0, 0, 0};

    // space is a special char: it is the only key that is not in the "layers"
    if (matrix[SPACE]){ // Space
        if (matrix[SHIFT_LAYER]) char_to_report('_', hid_report);
        else                     char_to_report(' ', hid_report);
    }

    // check if "change layer" key is pressed.
    // if true, look at the keys in the layer
    if (matrix[SYMB_LAYER]) {
        matrix[SYMB_LAYER] = false;
        layer_to_report(_symb_layer, hid_report);
    }

    if (matrix[NUM_LAYER]) {
        matrix[NUM_LAYER] = false;
        layer_to_report(_num_layer, hid_report);
    }

    if (matrix[SHIFT_LAYER]) {
        matrix[SHIFT_LAYER] = false;
        if (matrix[35]) { hid_report[0] = 0b00000010;};
        layer_to_report(_shift_layer, hid_report);
    }

    if (matrix[FUNC_LAYER]) {
        matrix[FUNC_LAYER] = false;
        layer_to_report(_func_layer, hid_report);
    }

    // if no layer key pressed, send chars from the default layout
    layer_to_report(_base_layer, hid_report);

    // send additional modifiers (alt, super, ctrl)
    modifiers_to_report(
       matrix[MODIFIER_CTRL],
       false, // no shift: shift is a layering key now
       matrix[MODIFIER_ALT],
       matrix[MODIFIER_SUPER],
       hid_report
    );

    // send the report via usb
    send_keys(hid_report);
    send_keys_ble(hid_report);
}

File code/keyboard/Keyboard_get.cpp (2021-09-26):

#include "Keyboard_get.h"

bool matrix[48];
RotaryEncoderSignal rotary_encoder;
bool rotary_last_on_on;

/*
 * MULTIPLEXER:
 * our multiplexers have 2 buffers, representing the 16 pins.
 * each can be input/output.
 * you can define each pin as output or input.
 *
 * to do something:
 * - you first send the adress (Wire.beginTransmission(adress))
 * - then you send the "command" byte (0x06 for define first buffer, 0x07 for define second buffer, 0x02/3 to write, 0x00/1 to read)
 * - you send the "data" byte, representing the bits that you want
 * - then you endTransmission
 *
 */

void setup_i2c() {
    Wire.begin();

    // define inputs/outputs pins in the left multiplexer
    Wire.beginTransmission(LEFT_I2C);
    Wire.write(0x06);
    Wire.write(0b11000000);
    Wire.endTransmission();

    Wire.beginTransmission(LEFT_I2C);
    Wire.write(0x07);
    Wire.write(0b00001111); // 0 = output, 1 = input
    Wire.endTransmission();

    // define inputs/outputs pins in the right multiplexer
    Wire.beginTransmission(RIGHT_I2C);
    Wire.write(0x06);
    Wire.write(0b11000000);
    Wire.endTransmission();

    Wire.beginTransmission(RIGHT_I2C);
    Wire.write(0x07);
    Wire.write(0b00001111);
    Wire.endTransmission();
}


byte getLine(int adress, uint8_t line) // return the byte 00abcdef
{
    // set the requested line to high,
    // everything else to low
    Wire.beginTransmission(adress);
    Wire.write(0x03);
    byte pin = 4 + line;
    Wire.write(~ (1<<pin));
    Wire.endTransmission();

    // request state of buffer 1
    Wire.beginTransmission(adress);
    Wire.write(0x00);
    Wire.endTransmission();

    Wire.requestFrom(adress, 1);
    byte buff0 = Wire.read();
    Wire.endTransmission();

    // request state of buffer 2
    Wire.beginTransmission(adress);
    Wire.write(0x01);
    Wire.endTransmission();

    Wire.requestFrom(adress, 1);
    byte buff1 = Wire.read();
    Wire.endTransmission();


    if (adress == RIGHT_I2C) {
        // dirty optimization: look if there is a rotary_encoder signal
        bool s1 = (~buff0 & 0b00100000) != 0;
        bool s2 = (~buff0 & 0b00010000) != 0;

        if (s1 && !s2 && rotary_last_on_on) {
            // on-on -> on-off: right rotation
            rotary_encoder = RE1;
        }
        else if (s2 && !s1 && rotary_last_on_on) {
            // on-on -> off-on : left rotation
            rotary_encoder = RE2;
        }
        rotary_last_on_on = s1 && s2;
    }

    // put together the 2 outputs:
    // return value = byte between 0b000000 and 0b111111

    // we want = abdcef (state of keyboard on that line)
    // buff0 = efxxxxxx
    // buff1 = xxxxabcd
    return ~((buff0 & 0b11000000) >> 6 | (buff1 & 0b00001111) << 2);
}

int read_keys() {
    int total_keys_pressed = 0; 

    // for each line, get the data from the 2 sides
    for (int y=0; y<4; y++)
    {
        byte left = getLine(LEFT_I2C, y);
        byte right = getLine(RIGHT_I2C, y);

        // then combine them to fill the `matrix` table
        for (int x=0; x<6; x++)
        {
            bool pressed = (left >> (5-x)) & 1;
            matrix[y*12+x] = pressed;
            total_keys_pressed += pressed;
        }

        for (int x=0; x<6; x++)
        {
            bool pressed = (right >> (5-x)) & 1;
            matrix[y*12+6+x] = pressed;
            total_keys_pressed += pressed;
        }
    }
    return total_keys_pressed;
}

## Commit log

2021-04-21 renamed folder and changed pcb
    [splitboard-B_Cu.gbr, splitboard-B_Mask.gbr, splitboard-B_Paste.gbr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]
2021-04-21 added 3d models
    [Assemblage.SLDASM, left back.SLDPRT, left plate.SLDPRT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]
2021-04-21 added measures in pcb
    [splitboard.kicad_pcb]
2021-04-24 exported pcb to step/solidworks
    [Assemblage.SLDASM, left pcb.sldprt, left plate.SLDPRT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]
2021-04-24 plan de masse gauche
    [splitboard.kicad_pcb]
2021-04-24 original feather 32u4 pcb
    [Adafruit Feather 32u4 Bluefruit LE.kicad_pcb, Adafruit Feather 32u4 Bluefruit LE.sch]
2021-04-24 changed dimensions
    [Assemblage.SLDASM, left back.SLDPRT, left plate.SLDPRT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]
2021-04-25 plan de masse droite
    [splitboard.kicad_pcb]
2021-04-25 added .step of 3d model
    [Assemblage.STEP]
2021-04-25 check wires
    [splitboard.kicad_pcb]
2021-04-29 check wires and gnd
    [splitboard.kicad_pcb]
2021-04-29 added hole for screws in kicad
2021-04-29 updated pcb and holes
    [Assemblage.SLDASM, left back.SLDPRT, left pcb.sldprt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]
2021-04-30 changed hole dimensions
2021-04-30 holes, dimensions and screws
    [Assemblage.SLDASM, left back.SLDPRT, left plate.SLDPRT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]
2021-04-30 holes dimensions
    [splitboard.kicad_pcb]
2021-04-30 added screws, spacers and nuts
    [Assemblage.SLDASM, Assemblage.STEP, left back.SLDPRT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]
2021-05-01 pcb origin
    [splitboard-B_Cu.gbr, splitboard-B_Mask.gbr, splitboard-B_Paste.gbr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]
2021-05-01 pcb via
    [splitboard-B_Cu.gbr, splitboard-B_Mask.gbr, splitboard-B_Paste.gbr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]
2021-05-22 exported for cnc
    [left plate simple.SLDPRT, left plate.STEP, right plate simple.STEP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]
2021-05-23 exported spacer for 3D printing
    [Assemblage.SLDASM, left back.SLDPRT, left plate.SLDPRT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]
2021-05-24 last revision before machining
    [left plate simple.SLDPRT, left plate.STEP, right plate simple.STEP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]
2021-06-01 finitions for plate and 3d printed support
    [Assemblage.SLDASM, left back.SLDPRT, left plate.SLDPRT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]
2021-06-01 removed useless files
    [Assemblage.STEP, pcb.step, spacer.STEP]
2021-06-08 for printing
    [Assemblage.SLDASM, left back.SLDPRT, right back.SLDPRT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]
2021-06-09 modifications for cable
    [Assemblage.SLDASM, left back.SLDPRT, left back.STEP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]
2021-06-18 added stl files for keycaps
    [row_1.stl, row_2.stl, row_3.stl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]
2021-08-27 fixed bug with layer keys
    [Keyboard_ble.cpp, Keyboard_get.cpp, keyboard.ino]
2021-08-27 fixed same layer bug with space key
    [keyboard.ino]
2021-09-26 added option to change keymap with rotary encoder
2021-10-02 Fixed bluetooth issue and switched azerty and qwerty
    [Keyboard_ble.cpp, keyboard.ino]
